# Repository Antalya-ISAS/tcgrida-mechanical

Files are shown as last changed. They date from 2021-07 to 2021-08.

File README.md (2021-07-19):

# Antalya ISAS

## tcGrida's remote-control, vehicle codes, and circuit designs. 


     

### What is tcGrida?
tcGrida is an explorer ROV that is capable of long duration and long-distance dives, autonomous emergency easy-surface*, live video feed, 4K@60 video recording, high-pressure durable and waterproof design with a wired, trustable and stable connection.

*: A solution that prevents your vehicle from getting lost in the water when the connection is lost and makes it get back to the surface autonomously.

## Our Social Media Accounts, Website and Discord Server

 Instagram: https://instagram.com/antalya.isas
 
 LinkedIn: https://linkedin.com/company/antalya-isas

 YouTube: https://www.youtube.com/channel/UCWZvgA6EhvlmvoRbStbpwaQ

 Website: https://antalyaisas.com

 Discord Server: https://discord.gg/peCKe2drMV

## Contact

E-mail: info@antalyaisas.com

Contact Form: https://antalyaisas.com/iletisim.html

Address: [Molla Yusuf Mah. Hürriyet Cad. No: 25 Konyaaltı/Antalya, Türkiye](https://goo.gl/maps/5YjF16fynHth8VVB9)

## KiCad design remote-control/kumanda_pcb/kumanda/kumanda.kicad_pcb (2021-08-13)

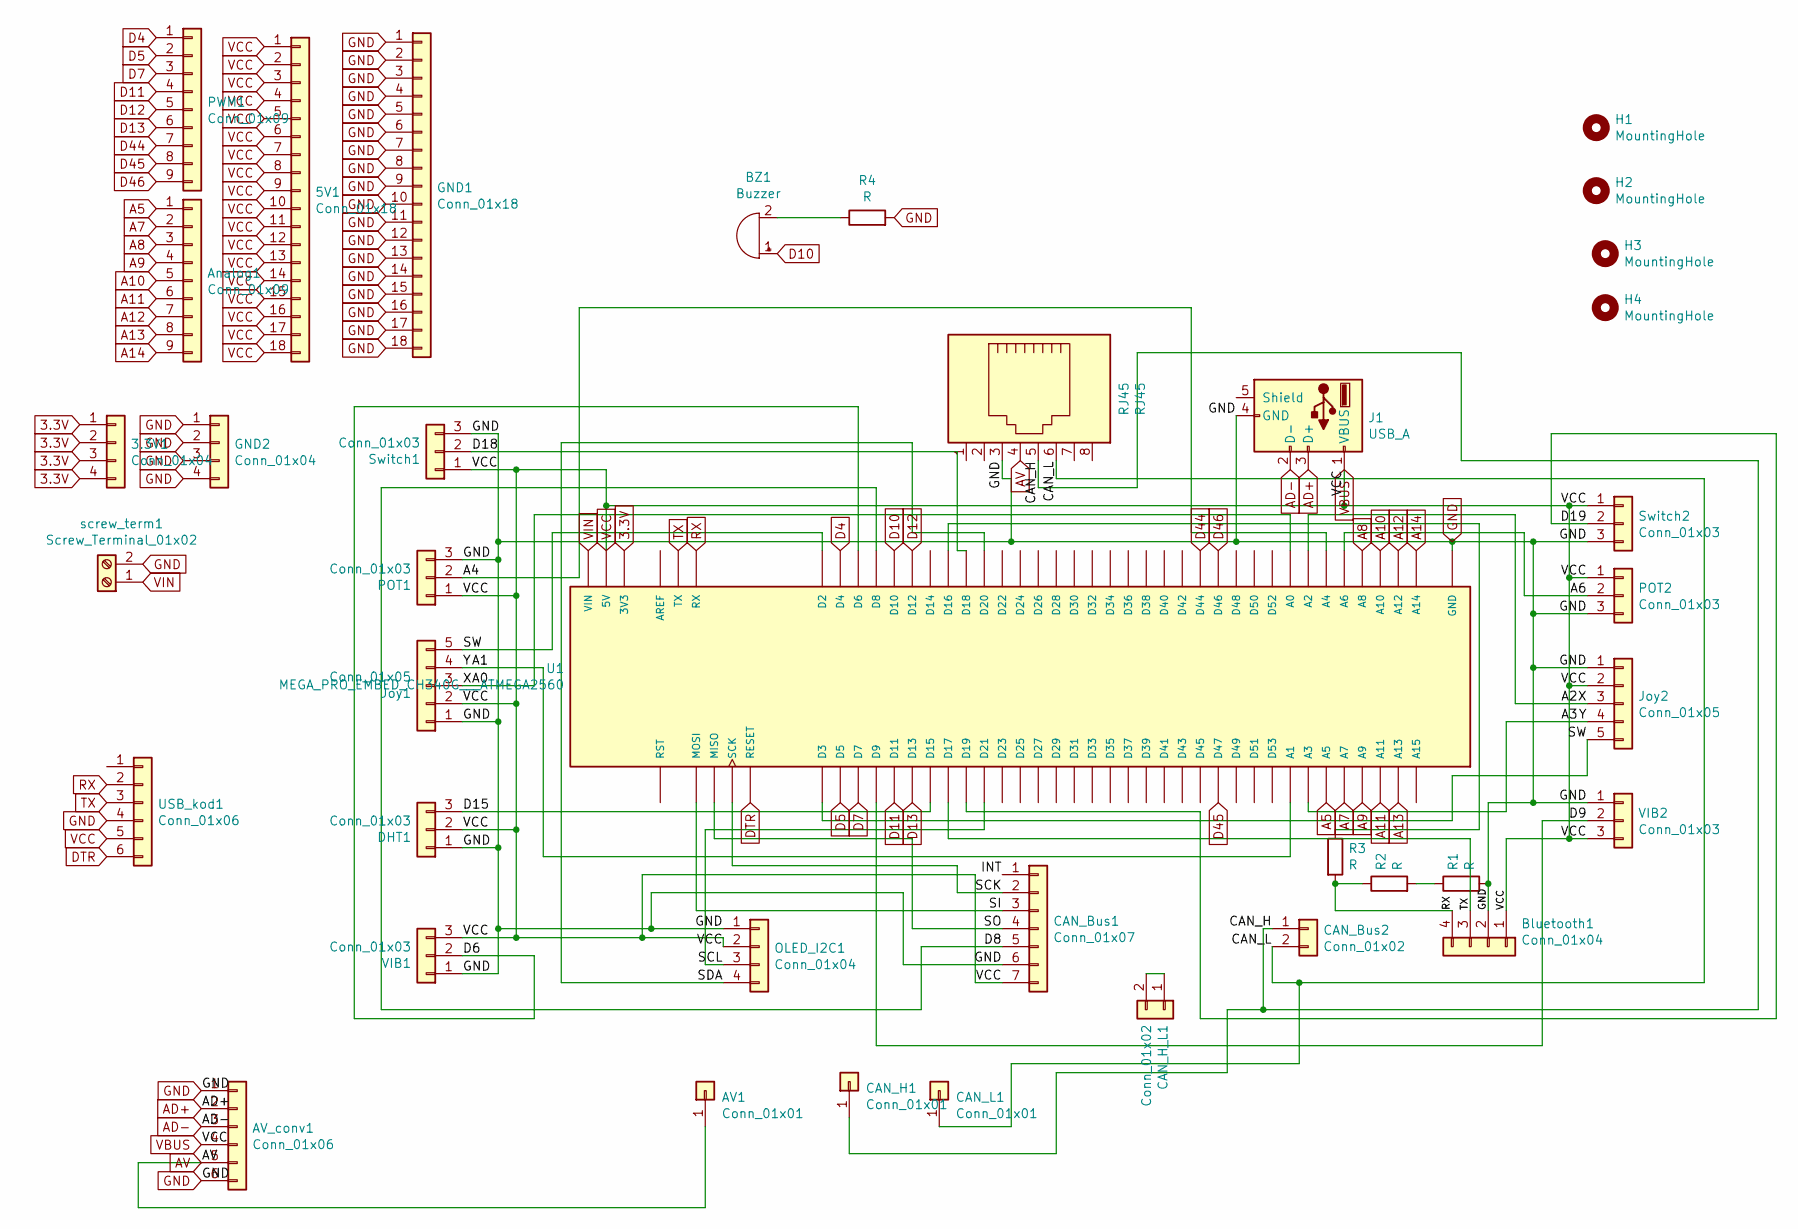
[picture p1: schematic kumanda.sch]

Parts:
3.3V1: Conn_01x04; PinHeader_1x04_P2.54mm_Vertical
5V1: Conn_01x18; PinHeader_1x18_P2.54mm_Vertical
AV1: Conn_01x01; PinHeader_1x01_P2.54mm_Vertical
AV_conv1: Conn_01x06; Analog-cam
Analog1: Conn_01x09; PinHeader_1x09_P2.54mm_Vertical
BZ1: Buzzer; Buzzer_12x9.5RM7.6
Bluetooth1: Conn_01x04; JST_XH_B4B-XH-A_1x04_P2.50mm_Vertical
CAN_Bus1: Conn_01x07; PinHeader_1x07_P2.54mm_Vertical
CAN_Bus2: Conn_01x02; PinHeader_1x02_P2.54mm_Vertical
CAN_H1: Conn_01x01; PinHeader_1x01_P2.54mm_Vertical
CAN_H_L1: Conn_01x02; PinHeader_1x02_P2.54mm_Vertical
CAN_L1: Conn_01x01; PinHeader_1x01_P2.54mm_Vertical
DHT1: Conn_01x03; JST_XH_B3B-XH-A_1x03_P2.50mm_Vertical
GND1: Conn_01x18; PinHeader_1x18_P2.54mm_Vertical
GND2: Conn_01x04; PinHeader_1x04_P2.54mm_Vertical
H1, H2, H3, H4: MountingHole; MountingHole_3.2mm_M3
J1: USB_A; USB_A_CONNFLY_DS1095-WNR0
Joy1, Joy2: Conn_01x05; JST_XH_B5B-XH-A_1x05_P2.50mm_Vertical
OLED_I2C1: Conn_01x04; JST_XH_B4B-XH-A_1x04_P2.50mm_Vertical
POT1, POT2: Conn_01x03; JST_XH_B3B-XH-A_1x03_P2.50mm_Vertical
PWM1: Conn_01x09; PinHeader_1x09_P2.54mm_Vertical
R1, R2, R3, R4: R; R_Axial_DIN0207_L6.3mm_D2.5mm_P7.62mm_Horizontal
RJ45: RJ45; RJ45_Ninigi_GE
Switch1, Switch2: Conn_01x03; JST_XH_B3B-XH-A_1x03_P2.50mm_Vertical
U1: MEGA_PRO_EMBED_CH340G___ATMEGA2560; _ATMEGA2560; PARTREV 12/May/2017
USB_kod1: Conn_01x06; PinHeader_1x06_P2.54mm_Vertical
VIB1, VIB2: Conn_01x03; JST_XH_B3B-XH-A_1x03_P2.50mm_Vertical
screw_term1: Screw_Terminal_01x02; TerminalBlock_Phoenix_PT-1,5-2-3.5-H_1x02_P3.50mm_Horizontal

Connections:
3.3V: 3.3V1.1, 3.3V1.2, 3.3V1.3, 3.3V1.4, U1.3V3_1 (3V3), U1.3V3_2 (3V3)
/A0: Joy1.3, Joy2.3, U1.A0, U1.A2
/A1: Joy1.4, Joy2.4, U1.A1, U1.A3
/A4: POT1.2, U1.A4
/A6: POT2.2, U1.A6
/CAN_H: CAN_Bus2.1, CAN_H1.1, RJ45.5
/CAN_L: CAN_Bus2.2, CAN_L1.1, RJ45.6
/D6: U1.D6, VIB1.2
/D8: CAN_Bus1.5, U1.D8
/D9: U1.D9, VIB2.2
/D15: DHT1.3, U1.D15
/D18: Switch1.2, U1.D18
/D19: Switch2.2, U1.D19
/INT: CAN_Bus1.1
/SCK: CAN_Bus1.2, U1.SCK
/SCL: OLED_I2C1.3, U1.D21
/SDA: OLED_I2C1.4, U1.D20
/SI: CAN_Bus1.3, U1.MOSI
/SO: CAN_Bus1.4, U1.MISO
/SW: Joy1.5, Joy2.5, U1.D2, U1.D3
A5: Analog1.1, U1.A5
A7: Analog1.2, U1.A7
A8: Analog1.3, U1.A8
A9: Analog1.4, U1.A9
A10: Analog1.5, U1.A10
A11: Analog1.6, U1.A11
A12: Analog1.7, U1.A12
A13: Analog1.8, U1.A13
A14: Analog1.9, U1.A14
AD+: AV_conv1.2, J1.3 (D+)
AD-: AV_conv1.3, J1.2 (D-)
AV: AV1.1, AV_conv1.5, RJ45.4
D4: PWM1.1, U1.D4
D5: PWM1.2, U1.D5
D7: PWM1.3, U1.D7
D10: BZ1.1 (-), U1.D10
D11: PWM1.4, U1.D11
D12: PWM1.5, U1.D12
D13: PWM1.6, U1.D13
D44: PWM1.7, U1.D44
D45: PWM1.8, U1.D47
D46: PWM1.9, U1.D46
DTR: U1.RESET, USB_kod1.6
GND: AV_conv1.1, AV_conv1.6, Bluetooth1.2, CAN_Bus1.6, DHT1.1, GND1.1, GND1.2, GND1.3, GND1.4, GND1.5, GND1.6, GND1.7, GND1.8, GND1.9, GND1.10, GND1.11, GND1.12, GND1.13, GND1.14, GND1.15, GND1.16, GND1.17, GND1.18, GND2.1, GND2.2, GND2.3, GND2.4, J1.4 (GND), Joy1.1, Joy2.1, OLED_I2C1.1, POT1.3, POT2.3, R1.2, R4.2, RJ45.3, Switch1.3, Switch2.3, U1.GND_1 (GND), U1.GND_2 (GND), U1.GND_3 (GND), USB_kod1.4, VIB1.1, VIB2.1, screw_term1.2
unnamed: BZ1.2 (+), R4.1
unnamed: CAN_H_L1.1, CAN_H_L1.2
unnamed: R1.1, R2.2
unnamed: R3.1, U1.D16
RX: Bluetooth1.4, R2.1, R3.2, U1.RX, USB_kod1.2
TX: Bluetooth1.3, U1.D17, U1.TX, USB_kod1.3
VBUS: 5V1.1, 5V1.2, 5V1.3, 5V1.4, 5V1.5, 5V1.6, 5V1.7, 5V1.8, 5V1.9, 5V1.10, 5V1.11, 5V1.12, 5V1.13, 5V1.14, 5V1.15, 5V1.16, 5V1.17, 5V1.18, AV_conv1.4, Bluetooth1.1, CAN_Bus1.7, DHT1.2, J1.1 (VBUS), Joy1.2, Joy2.2, OLED_I2C1.2, POT1.1, POT2.1, Switch1.1, Switch2.1, U1.5V_1 (5V), U1.5V_2 (5V), U1.5V_3 (5V), USB_kod1.5, VIB1.3, VIB2.3
VIN: U1.VIN_1 (VIN), U1.VIN_2 (VIN), screw_term1.1

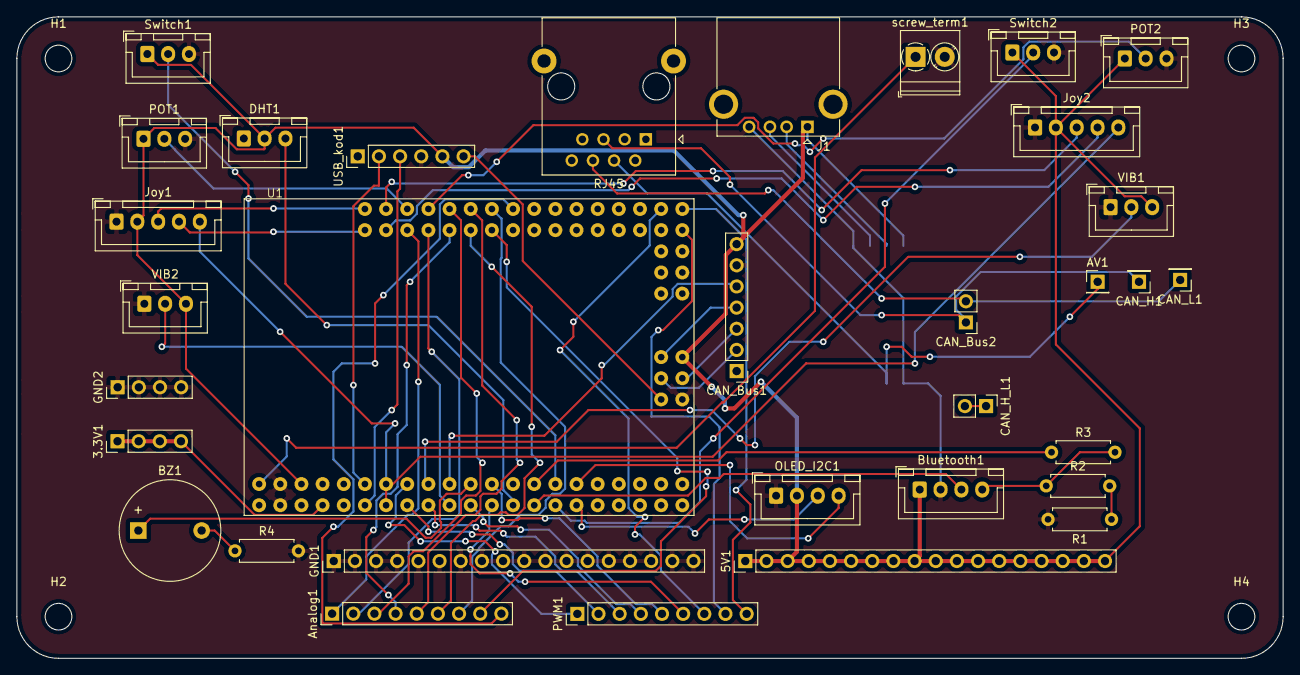
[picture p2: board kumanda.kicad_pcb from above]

Board: 2 copper layers, 152.0 x 77.0 mm, 38 parts (1 on the bottom side), 51 nets.

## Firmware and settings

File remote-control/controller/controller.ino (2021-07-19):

#include "logo.h"

#include <Adafruit_Sensor.h>
//#include <Adafruit_SSD1306.h>
#include <Adafruit_GFX.h>
#include <DHT.h>
#include <Wire.h>
#include <can.h>
#include <mcp2515.h>
#include <Servo.h>
#include <SPI.h>

#define maxdeger 1940 //max 2000 oluyor escler 1000-2000 arası calisir
#define mindeger 1060
#define sabitleme_toleransi 30
#define SCREEN_WIDTH 128 // OLED display width, in pixels
#define SCREEN_HEIGHT 64 // OLED display height, in pixels
#define OLED_RESET     1 // Reset pin # (or -1 if sharing Arduino reset pin)
Adafruit_SSD1306 display(SCREEN_WIDTH, SCREEN_HEIGHT, &Wire, OLED_RESET);

DHT dht(5,DHT11);

struct can_frame canSend;
struct can_frame canRcv;

MCP2515 mcp2515(8);
float hizBoleni = 1.0;
int button = 2;
int buttonDurum;
int sayac;
bool clear_state = true;
int dis_sicaklik;
int dis_nem;
int basinc_deger;
int sicak_deger;
unsigned long limit = 200;
unsigned long currentTime;
unsigned long previousTime;
int pinJoyStick_X_1 = 1;
int pinJoyStick_Y_1 = 0;
int pinJoyStick_X_2 = 2;
int pinJoyStick_Y_2 = 3;
int lcd_durum;
int valueJoyStick_X_1 = 0;
int valueJoyStick_Y_1 = 0;
int valueJoyStick_X_2 = 0;
int valueJoyStick_Y_2 = 0;


union ArrayToInteger {
  byte array[2];
  int integer;
} converter;
union ArrayToDouble {
  byte array[4];
  double number;
} doubler;




void setup()
{
  display.begin(SSD1306_SWITCHCAPVCC, 0x3C);  // initialize I2C addr to 0x3C ( for 128x64 Display )
  display.clearDisplay();
  
  display.drawBitmap(0, 0, isas_logo, 126, 60, WHITE); // show Antalya İSAS logo
  display.display(); 
  delay(3000);
  display.clearDisplay();
  
  Serial.begin(9600);
  SPI.begin();
  
  display.setTextSize(2); 
  display.setTextColor(WHITE);
  display.setCursor(10,24);
  display.println("TCG Grida");
  display.display();
  delay(5000);
  display.clearDisplay();
  
  pinMode(button , INPUT);
  attachInterrupt(digitalPinToInterrupt(button),lcd_state,RISING);
  mcp2515.reset();
  mcp2515.setBitrate(CAN_125KBPS, MCP_8MHZ);
  mcp2515.setNormalMode();
  dht.begin();

}

void lcd_state()
{
  previousTime = currentTime;
  clear_state = true;
  buttonDurum = 1;
  Serial.println(lcd_durum);
}

void loop()
{
  currentTime = millis();
  if (Serial.available())
  {
    int incomingByte = Serial.read();
    hizBoleni = incomingByte / 10.0;
  }

  // Araçtan gelen değerler bölünerek USB Üzerine yazılıyor.
  // Eğer araçtan bir bilgi yukarı gelecek ise bunu Can_ID'si üzerinden belirtmeniz gerekir.
  if (mcp2515.readMessage(&canRcv) == MCP2515::ERROR_OK)
  {
    if (canRcv.can_id == 0x03)
    {
      doubler.array[0] = canRcv.data[0];
      doubler.array[1] = canRcv.data[1];
      doubler.array[2] = canRcv.data[2];
      doubler.array[3] = canRcv.data[3];
      Serial.print('b'); // basinc belirteci
      Serial.println(doubler.number);
      basinc_deger = doubler.number;
      doubler.array[0] = canRcv.data[4];
      doubler.array[1] = canRcv.data[5];
      doubler.array[2] = canRcv.data[6];
      doubler.array[3] = canRcv.data[7];
      Serial.print('s'); // sicaklik belirteci
      Serial.println(doubler.number);
      sicak_deger = doubler.number;
    }
  }
  else{
    //Serial.println("hata");
    }
  
  dis_sicaklik = dht.readTemperature();
  dis_nem = dht.readHumidity();

  // Analogread 0-1023 arasında okuma yapar, burada esc değerleri olan 1000-2000 arasına eşitleniyor.
  // Herhangi bir joystick değerini 3000'den çıkarmak, joystick eksenini ters çevirme anlamına gelir.
  valueJoyStick_X_1 = analogRead(pinJoyStick_X_1) + 1000;
  valueJoyStick_Y_1 = 3000 - (analogRead(pinJoyStick_Y_1) + 1000);
  valueJoyStick_X_2 = analogRead(pinJoyStick_X_2) + 1000;
  valueJoyStick_Y_2 = 3000 - (analogRead(pinJoyStick_Y_2) + 1000);
  // Joystick değerlerini merkezi değiştirmeden bölme işlemleri
  valueJoyStick_X_1 = 1500 + (valueJoyStick_X_1 - 1500) / hizBoleni;
  valueJoyStick_Y_1 = 1500 + (valueJoyStick_Y_1 - 1500) / hizBoleni;
  valueJoyStick_X_2 = 1500 + (valueJoyStick_X_2 - 1500) / hizBoleni;
  valueJoyStick_Y_2 = 1500 + (valueJoyStick_Y_2 - 1500) / hizBoleni;
  
  if (valueJoyStick_X_1 > maxdeger) valueJoyStick_X_1 = maxdeger;
  if (valueJoyStick_Y_1 > maxdeger) valueJoyStick_Y_1 = maxdeger;
  if (valueJoyStick_X_2 > maxdeger) valueJoyStick_X_2 = maxdeger;
  if (valueJoyStick_Y_2 > maxdeger) valueJoyStick_Y_2 = maxdeger;

  if (valueJoyStick_X_1 < mindeger) valueJoyStick_X_1 = mindeger;
  if (valueJoyStick_Y_1 < mindeger)valueJoyStick_Y_1 = mindeger;
  if (valueJoyStick_X_2 < mindeger) valueJoyStick_X_2 = mindeger;
  if (valueJoyStick_Y_2 < mindeger)valueJoyStick_Y_2 = mindeger;

  // joystick'ler belli bi toleransla ortadayken 1500'e sabitliyoruz
  if (valueJoyStick_X_1 < 1500 + sabitleme_toleransi / hizBoleni && valueJoyStick_X_1 > 1500 - sabitleme_toleransi / hizBoleni)
    valueJoyStick_X_1 = 1500;
  if (valueJoyStick_Y_1 < 1500 + sabitleme_toleransi / hizBoleni && valueJoyStick_Y_1 > 1500 - sabitleme_toleransi / hizBoleni)
    valueJoyStick_Y_1 = 1500;
  if (valueJoyStick_X_2 < 1500 + sabitleme_toleransi / hizBoleni && valueJoyStick_X_2 > 1500 - sabitleme_toleransi / hizBoleni)
    valueJoyStick_X_2 = 1500;
  if (valueJoyStick_Y_2 < 1500 + sabitleme_toleransi / hizBoleni && valueJoyStick_Y_2 > 1500 - sabitleme_toleransi / hizBoleni)
    valueJoyStick_Y_2 = 1500;
  // Joystick degerleri 8 byte'a siralanip yollaniyor
  canSend.can_id = 0x02;
  canSend.can_dlc = 8;
  canSend.data[0] = highByte(valueJoyStick_X_1);
  canSend.data[1] = lowByte(valueJoyStick_X_1);
  canSend.data[2] = highByte(valueJoyStick_Y_1);
  canSend.data[3] = lowByte(valueJoyStick_Y_1);
  canSend.data[4] = highByte(valueJoyStick_X_2);
  canSend.data[5] = lowByte(valueJoyStick_X_2);
  canSend.data[6] = highByte(valueJoyStick_Y_2);
  canSend.data[7] = lowByte(valueJoyStick_Y_2);

  // q-w-e-r her degerin bilgisayardan ayirt edilmesi icin ayri kodlar
  /*Serial.print("X1");
  Serial.println(valueJoyStick_X_1);
  Serial.print("Y1");
  Serial.println(valueJoyStick_Y_1);
  Serial.print("X2");
  Serial.println(valueJoyStick_X_2);
  Serial.print("Y2");
  Serial.println(valueJoyStick_Y_2);
  */
  unsigned long sonuc = currentTime - previousTime;
  if (buttonDurum == 1 && sonuc >= limit)
  {
    sayac++;
    buttonDurum = 0;
  }
  
  if(sayac%3 == 0)
  {
      if(clear_state == true) display.clearDisplay();
      clear_state = false;
    //her harfin eni 12 piksel dolayısıyla karakter sayısı x 12+2(2 boşluk bırakmak için gerekiyor) yeni cursor posziyonu
    // (:) işaretini alandan kazanmak için özel cursor yeri belirleyerek yazdım 3-4 pixel kazandık böylece diper türlü önceki kelimenin son harfi ve (:) arasında çok boşluk oluyordu.
      display.setTextSize(2); 
      display.setTextColor(WHITE);
      display.setCursor(0,16);
      display.print("Derinlik");
      display.setCursor(90, 16);
      display.print(":");
      display.setCursor(99, 16);
      display.print(basinc_deger); //pressure value
    
      display.setCursor(0,32);
      display.print("Sicaklik:");
      display.setCursor(90, 32);
      display.print(":");
      display.setCursor(99,32);
      display.print(sicak_deger); //temp value
      display.display();
      
  }
  
  else if(sayac%3 == 1)
  {
    if(clear_state == true) display.clearDisplay();
    clear_state = false;
    
    display.setCursor(0,0);
    display.print("   Bilgi");
    display.setCursor(22,16);
    display.print("x1:");
    display.setCursor(58,16);
    display.print(valueJoyStick_X_1);
    display.setCursor(22,32);
    display.print("x2:");
    display.setCursor(58,32);
    display.print(3000 - (valueJoyStick_X_2)); 
    display.setCursor(22,48);
    display.print("y2:");   
    display.setCursor(58,48);
    display.print(valueJoyStick_Y_2);
    display.display();
  }
    // Show humidity level
   if(sayac%3 == 2)
   {
  if(clear_state == true) display.clearDisplay();
  clear_state = false;
  display.drawRect(2,17,126,46,WHITE);
  display.drawLine(2,40,126,40,WHITE);
  display.drawLine(48,17,48,62,WHITE);

  
  display.setCursor(0,0);
  display.print("Cevre Blg.");
   // Show temperature level (Celcius)
  if (dis_sicaklik < 10)
  { 
    display.setCursor(5, 22);
    display.print("Sic");
    display.setCursor(39, 22);
    display.print(":");
    display.setCursor(53, 22);
    display.print("0");
    display.setCursor(82, 22);
    display.print(dis_sicaklik);
    display.setCursor(96,22);
    display.print("C");
  }
  else
  {
    display.setCursor(5, 22);
    display.print("Sic");
    display.setCursor(39, 22);
    display.print(":");
    display.setCursor(68, 22);
    display.print(dis_sicaklik);
    display.print("C");
  }

  // Show humidity level 
  if (dis_nem< 10)
  {
    display.setCursor(5, 44);
    display.print("Nem");
    display.setCursor(39, 44);
    display.print(":");
    display.setCursor(68, 44);
    display.print("%");
    display.setCursor(82, 44);
    display.print(0);
    display.setCursor(96,44);
    display.print(dis_nem);
  }
  else
  { 
    display.setCursor(5, 44);
    display.print("Nem");
    display.setCursor(39, 44);
    display.print(":");
    display.setCursor(68, 44);
    display.print("%");
    display.setCursor(82, 44);
    display.print(dis_nem);

  }
  display.display();
   
  }
  if(sayac >= 3)sayac = 0;
  
  mcp2515.sendMessage(&canSend);
  delay(20);
  
}

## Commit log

2021-07-19 Move mechanical stuff to here from https://github.com/antalya-isas/tcgrida-app
    [kumanda.kicad_pcb, kumanda.sch]
2021-08-13 PCB design finished.
    [kumanda.kicad_pcb, kumanda.sch]

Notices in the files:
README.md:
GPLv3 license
